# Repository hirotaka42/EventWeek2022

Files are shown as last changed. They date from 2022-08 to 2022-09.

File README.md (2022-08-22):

# 技育展2022_ハード/組み込み_個人開発

## 作品名

遠隔操作は意外と身近なもので

## 概要

`IoT` x `モビリティ` x `安全性` x `Society 5.0` をテーマにした 人とインターネットの可能性を表現するプロジェクト

制作理由：    
- 現場作業や危険な場所での作業を遠隔地から安全に操作することによって、作業者の`危険`を少しでも排除したい,コンペとして個人開発で出来ることを探し挑戦しました.

取り組んだ内容:    
- 情報の俯瞰
   - カメラを使用した全体の状況把握
   - 車体や現場に取り付けたセンサデータを収集し操縦者へリアルタイムでの可視化 
- 遠隔操作
   - IoT通信プロトコル MQTTを用いたlowコストかつ低遅延な通信の実装
   - 低速ネットワークにおける操作のテスト
- 今までにない新たな取り組み
   - 未定(2022-08-22)
   - 未定(2022-08-22)
- その他アピール点
   - 技育展の展示として他方面の方にも興味を持ってもらう為に 作りやすさを意識した遠隔操作の実装

## 使用の仕方
    各ページに記載があります。

## ディレクトリ紹介

- ディレクトリ名
    - 概要
    - README.MD LINK [Open ↗︎](./RPI/Automation/Excavator/)

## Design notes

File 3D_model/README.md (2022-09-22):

# 3Dモデル

## 概要:

ベースは以下の教育向けFreeデータを使用  

https://www.thingiverse.com/thing:1015238

1台につきサーボモータを3つ使用

- [TowerPro-MG90S](https://akizukidenshi.com/catalog/g/gM-13227/) ￥850 x1
    - 台座に使用
- [TowerPro-SG92R](https://akizukidenshi.com/catalog/g/gM-08914/) ￥500 x2
    - アーム制御(R/L)に使用

## 3Dデータについて

R/Lのサーボ止めは既存のものだと小さいので `ArmServoStoper.stl` を使用してみてください。  
ショベル先端はお好みで印刷してください。

1台のデータを全て印刷するのに1台の3Dプリンタだと約30時間かかります。

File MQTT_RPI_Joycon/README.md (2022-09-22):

# MQTTとjoyconを用いた遠隔制御のプログラム

## 概要:
CloudMQTTを用いてjooyconの操作を
PublisherからSubscriverへ送るプログラム

- PubJoycon.py からメッセージをBrokerへtopic宛にSend
- SubJoycon.py でtopicを建てBrokerからtopic宛のメッセージを受信し制御

本プログラムにおいて、TLS/SSL 通信におけるCAはRPIのCAを使用しています.    
適宜パスを置き換えてください.

[How do I connect using TLS/SSL? ↗︎](https://www.cloudmqtt.com/docs/faq.html)

## 関係図:

- 役職
    - 担当機体
    - ->概要
- Publisher
    - RPI(PubJoycon.py) or Websocket UI(CloudMQTT console内に存在)でも代用可能
    - ->joyconのボタンデータを(Brokerへ)送信 
- Broker
    - CloudMQTT 
    - ->別のクライアント(Publisher)からの要求(topic)に従ってデータを(Subscriverへ)送信
- Subscriver
    - RPI(SubJoycon.py)
    - ->Brokerからデータを受け取り制御

## 処理の流れ

    - joyconのボタンデータがjoyconPub.pyを通じてCloud上のbroker(CloudMQTT)へ送信、
    - Cloud上のbroker(CloudMQTT)は,送信されてきたtopic宛Subscriver(SubJoycon.py)にボタンデータを送信
    - Subscriver(SubJoycon.py)は自分のtopic宛に送られたデータを受信し制御へ

## 使用の仕方

```bash:
# Step 1
# python venv環境(仮想化)と仮想化環境にモジュールのインストール
python3 -m venv venv && \
source ./venv/bin/activate && \
python3 -m pip install --upgrade pip && \
pip install -r requirements.txt

# Step 2
# プログラム実行(受信機:Subscriver)
python3 SubJoycon.py

# Step 3
# Bluetooth接続を先に実行し接続を確認してから
#Bluetooth 接続手順
sudo bluetoothctl              ... Bluetooth CTLを起動
remove D4:F0:57:D8:01:AE  ... 一旦ペアリング情報を削除
scan on                   ... デバイスをスキャン [CHG] Device XX:XX:XX:XX:XX:XX Name: Joy-Con (R) ジョイコン発見
pair D4:F0:57:D8:01:AE    ... 見つかったデバイスに対してペアリング要求
connect D4:F0:57:D8:01:AE ... connect
trust D4:F0:57:D8:01:AE   ... 次回起動時に自動接続できるよう、trustする
# プログラム実行(送信機:Publisher)
python3 PubJoycon.py

# 終了時
deactivate

# 2回目以降のvenv環境の再有効化
source ./venv/bin/activate
python3 PubJoycon.py
```

## 実行時

1. プログラム実行時、client.subscribe("SubscriberNAME")で設定した"SubscriberNAME"でメッセージを受信するために待機状態になります.

2. PublisherであるPubJoycon.pyで操作したjoyconボタンデータがCloudBroker(CloudMQTT)を介して,Subscriber(SubJoycon.py)宛にSendされます. 

3. Subscriber宛にSendされたメッセージはbyteで送られてくるため,UTF-8でデコードしメッセージの内容に応じて条件分岐などで処理をしてあげます.

ここまでが本プログラムの一連の流れです.

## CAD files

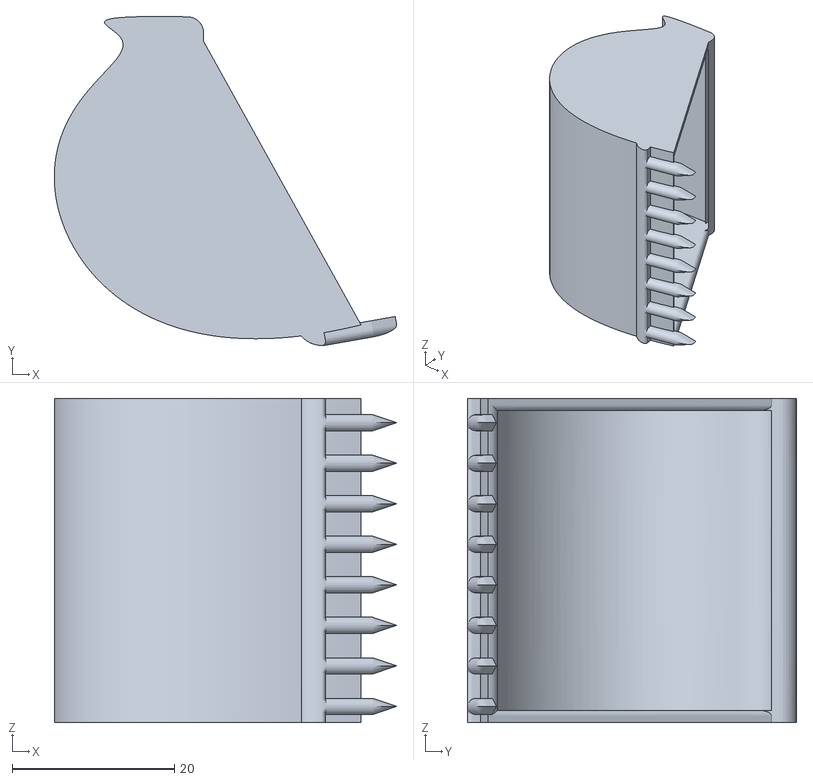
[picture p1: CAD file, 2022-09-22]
3D_model/ショベルKai1 v2.stl
42.2 x 40.6 x 40.0

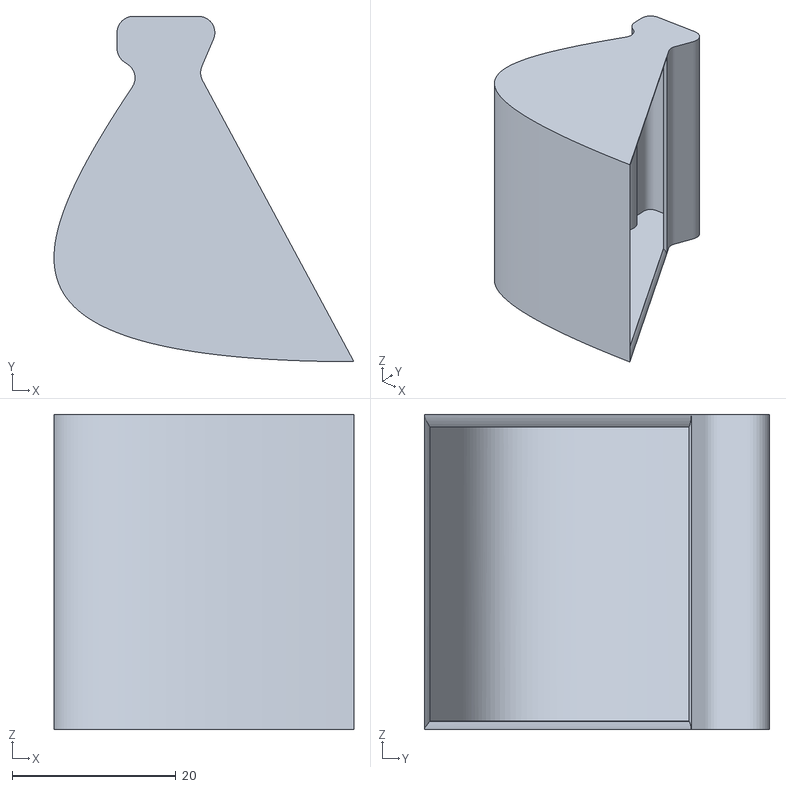
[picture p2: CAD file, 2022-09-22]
3D_model/ショベル v1.stl
36.7 x 42.2 x 38.5

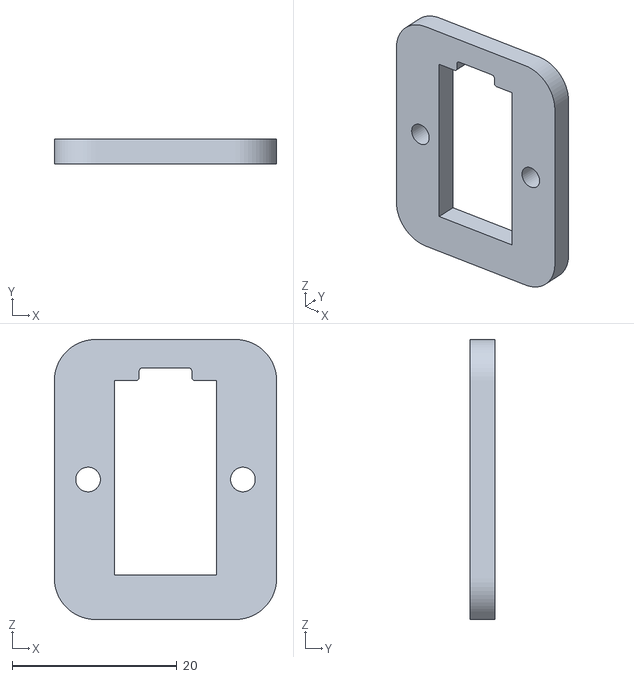
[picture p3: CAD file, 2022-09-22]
3D_model/ArmServoStoper v3.stl
27.0 x 3.00 x 34.0

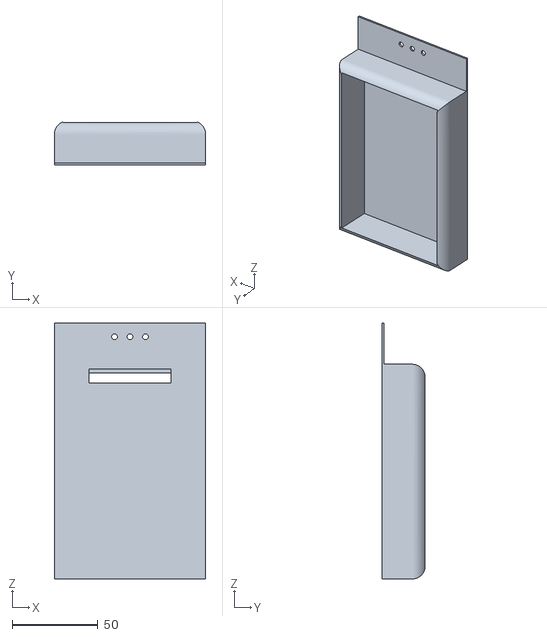
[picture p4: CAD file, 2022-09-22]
3D_model/Track_Box v3.stl
88.0 x 25.2 x 149.0

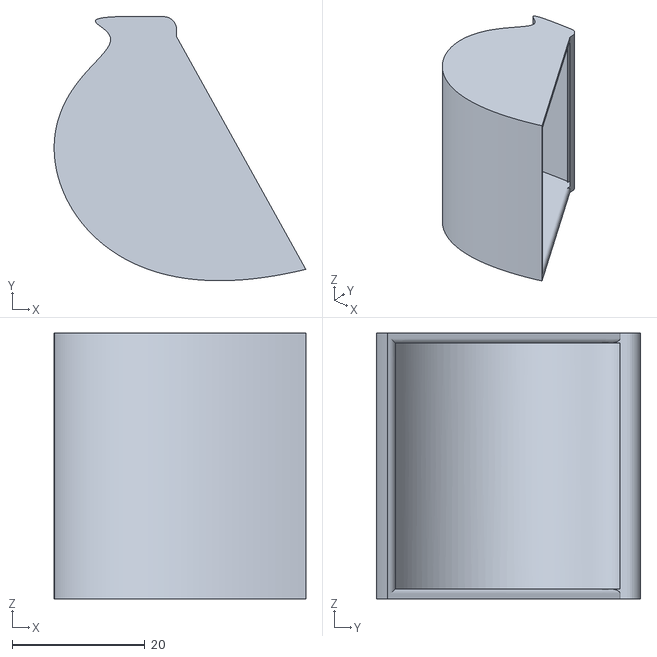
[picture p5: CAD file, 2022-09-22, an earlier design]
3D_model/ショベルKai1 v1.stl
37.8 x 39.8 x 40.0

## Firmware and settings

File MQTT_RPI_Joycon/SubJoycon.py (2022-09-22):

import random
import paho.mqtt.client as mqtt
from smbus2 import SMBus
import os
import sys
os.environ["SDL_VIDEODRIVER"] = "dummy"


"""
Joycon Sub
Brokerからデータを受信し,I2Cに命令を送るSubscriverプログラム

"""

"""初期設定：適宜書き換え"""
tls_ca = '/etc/ssl/certs/ca-certificates.crt'
broker = '接続先ブローカのホストネーム'
port = SSLポート番号
topic = "python/mqtt"
# generate client ID with pub prefix randomly
#client_id = f'python-mqtt-{random.randint(0, 1000)}'
username = 'ユーザ名'
password = 'パスワード'
"""初期設定：適宜書き換え"""


class InitClass:
    """
    初期設定クラス
    """

    def __init__(self):
        self._MOTER_R_I2C = 0x65
        self._MOTER_L_I2C = 0x60
        self.i2c = SMBus(1) 
        #SMBusの引数に1を指定する(なぜ？)
        #i2c検出 sudo i2cdetect -y 1 の "1"でi2cデバイスが見つかったため
        """
        Usage: i2cdetect [-y] [-a] [-q|-r] I2CBUS [FIRST LAST]
            i2cdetect -F I2CBUS
            i2cdetect -l
        I2CBUS is an integer or an I2C bus name
        If provided, FIRST and LAST limit the probing range.

        pi in front in ~ via 🐍 v2.7.16 via  254MiB/365MiB | 12MiB/100MiB 
        ❯$ sudo i2cdetect -l                                     
        i2c-1   i2c             bcm2835 (i2c@7e804000)                  I2C adapter
        
        raspberryPi3A+においてI2CBusは "i2c-1"を使用していた
        """
        

    def input_method(self,Flag,Bit):
        """
        Arg: Flag-> 0:STOP, 1:UP,  2:DOWN,
                    3:RIGHT,5:UP-R,7:DOWN-R,
                    4:LEFT, 6:UP-L,8:DOWN-L,
             Bit -> 停止:0xCB 正転:0xC9 逆転:0xCA
             説明:   DRV8830には、CONTORLレジスタ,FAULTレジスタがあります.
                    1:CONTORLレジスタに動作(正転,逆転,ブレーキ・惰走)と電圧(速度)を書き込むとモータが回転します.
                    2:動作論理表:
                    IN1:IN2:OUT1:OUT2:機能
                     0 : 0 : Z  : Z  :スタンバイ/惰走
                     0 : 1 : L  : H  :逆走
                     1 : 0 : Z  : L  :正転
                     1 : 1 : H  : H  :ブレーキ

                    3:電圧表
                    [P9のTable 1. Commanded Output Voltageを参考](https://www.tij.co.jp/jp/lit/ds/symlink/drv8830.pdf)
                    今回以下の組み合わせで使用
                    [機能 2bit]  :[電圧]               :[レジスタ書き込み値 8bit] 
                    正転   =0b10 : 4.02V=0x32=0b110010 :0b11001010=0xCA (電圧bitに対し2bit左シフトし機能bitを足す)
                    逆走   =0b01 : 4.02V=0x32=0b110010 :0b11001001=0xC9 (電圧bitに対し2bit左シフトし機能bitを足す)
                    ブレーキ=0b11 : 4.02V=0x32=0b110010 :0b11001011=0xCB (電圧bitに対し2bit左シフトし機能bitを足す)

        Return: None
        概要:引数Flag の値によって回転動作を処理する
        """
        
        if Flag == "STOP" or Flag == "UP" or Flag == "DOWN":
            self.i2c.write_byte_data(self._MOTER_R_I2C, 0, Bit)
            self.i2c.write_byte_data(self._MOTER_L_I2C, 0, Bit)
        elif Flag == "RIGHT" or Flag == "UP-R" or Flag == "DOWN-R":
            self.i2c.write_byte_data(self._MOTER_R_I2C, 0, 0xCB)
            self.i2c.write_byte_data(self._MOTER_L_I2C, 0, Bit)
        elif Flag == "LEFT" or Flag == "UP-L" or Flag == "DOWN-L":
            self.i2c.write_byte_data(self._MOTER_R_I2C, 0, Bit)
            self.i2c.write_byte_data(self._MOTER_L_I2C, 0, 0xCB)

        
class SettingClass:
    """
    モーターの動作設定クラス
    """

    def __init__(self):
        # InitClassのインスタンスを作成する
        self.initClass = InitClass()
    
    def FW_method(self):
        """
        概要:前に進む 
        """
        self.initClass.input_method("UP",0xC9)
        print("Run FW_method")
        

    def Rear_method(self):
        """
        概要:後ろに進む 
        """
        self.initClass.input_method("DOWN",0xCA)
        print("Run Rear_method")


    def R_method(self):
        """
        概要:Rに進む 
        """
        self.initClass.input_method("RIGHT",0xC9)
        print("Run R_method")
        

    def L_method(self):
        """
        概要:Lに進む 
        """
        self.initClass.input_method("LEFT",0xC9)
        print("Run L_method")

    def Rear_R_method(self):
        """
        """
        self.initClass.input_method("DOWN-R",0xCA)
        print("Run Rear_R_method")

    def Rear_L_method(self):
        """
        """
        self.initClass.input_method("DOWN-L",0xCA)
        print("Run Rear_L_method")

    def STOP_method(self):
        """
        elif event.type == pygame.JOYHATMOTION and event.value == (0, 0):
        """
        self.initClass.input_method("STOP",0xCB)
        print("Stop")


def control_i2c(bytesmsg):
    """

    """
    msg = bytesmsg.decode('utf-8')
    #SettingClassのインスタンスを作成
    setClass = SettingClass()

    print(msg)
    if msg == "FW":
        setClass.FW_method()
    elif msg == "ST":
        setClass.STOP_method()
    elif msg == "RE":
        setClass.Rear_method()
    elif msg == "L":
        setClass.L_method()
    elif msg == "R":
        setClass.R_method()
    elif msg == "RR":
        setClass.Rear_R_method()
    elif msg == "RL":
        setClass.Rear_L_method()
    else :
        setClass.STOP_method()
    

def connect_mqtt() -> mqtt:
    def on_connect(client, userdata, flags, rc):
        if rc == 0:
            print("Connected to MQTT Broker!")
        else:
            print("Failed to connect, return code %d\n", rc)

    client = mqtt.Client()
    client.on_connect = on_connect
    client.tls_set(tls_ca)
    client.username_pw_set(username, password)
    client.connect(broker, port)
    return client


def subscribe(client: mqtt):
    def on_message(client, userdata, msg):
        print(msg.topic+" "+str(msg.payload))
        control_i2c(msg.payload)


    client.subscribe(topic)
    client.on_message = on_message


def run():
    client = connect_mqtt()
    subscribe(client)
    client.loop_forever()


if __name__ == '__main__':
    run()

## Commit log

2022-01-11 [feature] 'DUAL-DRV8830' サンプルプログラム作成
2022-02-04 [feat: 遠隔操作を実装するためにRPIのI2CをJoyconで操作する処理を追加]
2022-02-04 feat: Make CameraView
2022-02-06 feat: MQTTのSubscriverを使用しLEDを制御するプログラム, first commit
2022-03-14 feat: SHT31を使用した温湿度計測プログラムの作成
2022-03-14 feat: 自動掘削機(ショベル)の制御プログラムを追加.
2022-03-19 feat: センサデータ保管用にリングバッファの追加
2022-03-19 feat: リングバッファのサイズを引数で指定できるように変更
2022-03-19 feat: python3.6以降のf-string(による文字列のフォーマットに変更
2022-03-19 clone: スイッチサイエンス公開のPython2.7用のサンプルプログラムをクローン
2022-03-19 fix: Python2.7から3.6以降の書き方に修正
2022-03-19 feat: BME280センサのクラス化
2022-03-19 feat: メモリリークを防ぐためBME280センサーデータの保持にリングバッファを追加
2022-03-19 feat: Server機能の実装に伴い、センサ取得とServer機能のスレッド化
2022-09-22 feat: RasPiにおけるMQTTプログラムの再作成
2022-09-22 Add: Create 3Dmodel.
    [ArmServoStoper v3.stl, Track_Box v3.stl, ショベル v1.stl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]
2022-09-22 feat: Readme.mdの追加
